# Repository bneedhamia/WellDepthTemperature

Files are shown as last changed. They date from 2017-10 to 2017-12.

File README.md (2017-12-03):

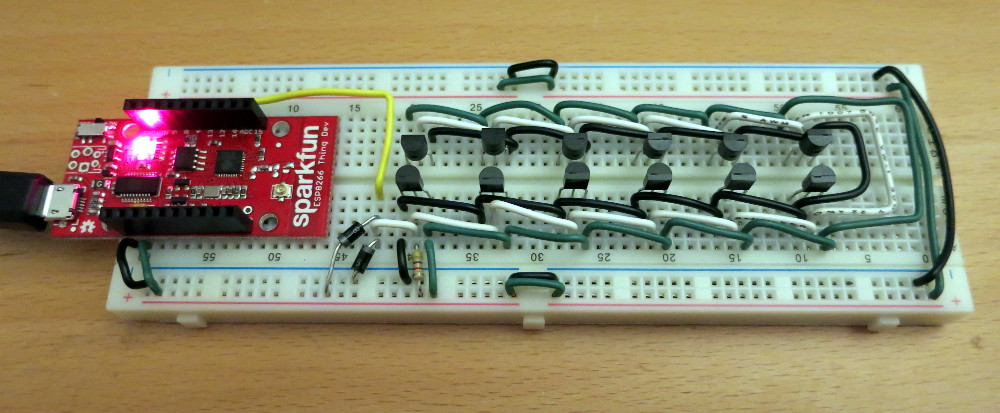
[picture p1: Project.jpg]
The Project so far

# WellDepthTemperature
An Arduino Sketch for a Sparkfun ESP8266 Thing Dev board, using multiple MAX31820 temperature sensors to estimate the height of water in a well tank.

This is a WORK IN PROGRESS. The state of the project: It currently connects to the local WiFi access point, reads the number of connected temperature sensors, and prints the 1-Wire address of each of them. It periodically reads the temperature from each of 12 sensors and performs an Https Post to a php page on needhamia.com that stores the data
in an SQL database. I'm designing the 3D printed junction boxes now, and soldering all the parts that will go into those boxes. See Diary.odt for details, remaining work, and progress.

Theory of operation: The side of the well tank is cooler below the level of the water than it is above that level. I plan to hot-glue a series of temperature sensors to the tank exterior, in a vertical line. Then I should be able to periodically measure the temperature at each sensor, estimate which sensors are below the water line, and translate that knowledge into an estimate of the level of the water in the tank.

I know that this method won't work when the ambient temperature of the well house is near the temperature of the water being pulled out of the well. I expect that won't be the case in the middle of a summer day, when we usually run out of water.

I chose this method over more reliable and direct methods because, compared to them, it's non-intrusive: I don't have to put anything in the tank, on the lid inside the tank, or in the pipes to or from the tank.

The current Arduino Sketch requires a Sparkfun ESP8266 Thing Dev board, a few MAX31820 temperature sensors, Cat6 cable, and some discrete parts (diodes, resistor). Details are in the .ino Sketch PIN_ definitions and in BillOfMaterials.ods.

Next steps: Construct the 1-wire bus and the plugs for the sensors.

## Files
* BillOfMaterials.ods = the parts list.
* BreadboardCase.FCStd = the FreeCAD design file for the ESP2866 circuit case (in progress). I will add the corresponding .stl files once I'm happy with the case design.
* createtables.sql = an SQL file to import into MySQL to create the well depth database table.
* diagrams.odp = project diagrams.
* Diary.odt = my journal/diary of the project, with design details.
* LICENSE = the project GPL2 license file.
* Project.jpg = a photo of the project so far.
* README.md = this file.
* ThreeJackCase.FCStd = the FreeCAD design file for the case for 3 RJ45 jacks.
* ThreeJackCaseBase.stl = the ready-to-print file for the base of the RJ45 case. Print right-side up, with no supports, raft, or brim. I designed it for PLA.
* ThreeJackCaseLid.stl = the ready-to-print file for the lid of the RJ45 case. Print UPSIDE-DOWN (lid top on the print bed), with no supports, raft, or brim. I designed it for PLA.
* webInstallation.odt = instructions on how to install the Sketch and web service.
* WellDepthTemperature.ino = the ESP8266 Arduino Sketch.
* WellDepthTemperature.fzz = the Fritzing (circuit wiring) diagram.
* welldepthconfig.php = site-specific PHP .ini-format configuration data, such as the sql database name.
Place this file in the same directory on your web site as welldepthpost.php.
* welldepthpost.php = the php web page that receives the Arduino's HTTPS POST request.

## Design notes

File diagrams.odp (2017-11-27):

## 1-Wire Bus Connections

Well Water Storage Tank

Senses ambient

temperature

Senses tank wall

temperature

= CAT6 cable

= MAX31820 sensor

= Three Jack Case

= Breadboard Case

ESP8266, etc.

Power (Mains)

plug

## Well Temperature Dataflow

MAX31820 Temperature

Sensors on the 1-wire bus

Server (Needhamia.com)

Server’s

PHP Web Service

MySQL

Database

ESP8266

Arduino Sketch

WiFi

Hotspot

HTTPS

Temperatures and

well tank depth estimate

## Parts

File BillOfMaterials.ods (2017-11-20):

Bill Of Materials for Well Depth Sensor |  | All values are in US Dollars
Count | Name | Supplier | Part Number | Cost each | Total | Url | Notes
1 | SparkFun ESP8266 Thing - Dev Board | Sparkfun | WRL-13711 | $15.95 | $15.95 | https://www.sparkfun.com/products/13711
2 | Arduino Stackable Header - 10 Pin | Sparkfun | PRT-11376 | $0.50 | $1.00 | https://www.sparkfun.com/products/11376 | To plug wires into the ESP8266 Thing Dev board
1 | Wall Adapter Power Supply - 5.1V DC 2.5A (USB Micro-B) | Sparkfun | TOL-13831 | $7.95 | $7.95 | https://www.sparkfun.com/products/13831 | This supply powers the ESP8266
12 | One-Wire Ambient Temperature Sensor - MAX31820 | Sparkfun | SEN-14049 | $1.95 | $23.40 |  | TODO finalise the number used. Available for a little less at Digikey: https://www.digikey.com/product-detail/en/maxim-integrated/MAX31820MCR/MAX31820MCR-ND/4271348
10 | Resistor 4.7K OHM 1/4W 5% AXIAL | Digikey | 4.7KQBK-ND | $0.06 | $0.60 | https://www.digikey.com/products/en?keywords=4.7KQBK-ND | We need only 1, but they're useful enough to buy at least 10
10 | Diode Standard 400V 1A Through Hole DO-41 | Digikey | 1N4004RLGOSCT-ND | $0.18 | $1.80 | https://www.digikey.com/product-detail/en/on-semiconductor/1N4004RLG/1N4004RLGOSCT-ND/822810 | Need only 2 for the 1-Wire bus, but they're useful enough to buy at least 10
1 | Breadboard - Self-Adhesive (Half size) | Sparkfun | PRT-12002 | $1.18 | $1.18 | https://www.sparkfun.com/products/12002
1 | Cable Matters Cat6 Snagless Ethernet Patch Cable in White 20 Feet (about 6 meters) | Amazon | B00G9BMZI4 | $14.99 | $14.99 | https://www.amazon.com/Cable-Matters-Snagless-Ethernet-Patch/dp/B00G9BMZI4 | You'll cut this and make your own cable ends. This is cheaper than bulk unless you need 300 meters or more
1 | Cable Matters (100-Pack) Cat 6 RJ45 Modular Plugs for Stranded UTP Cable | Amazon | B004D5RFCE | $12.95 | $12.95 | https://www.amazon.com/gp/product/B004D5RFCE
1 | Cable Matters 4-Pack RJ45 Color Coded Strain Relief Boots in Blue (50 Pieces per Pack) | Amazon | B0049QNV3E | $11.99 | $11.99 | https://www.amazon.com/Cable-Matters-4-Pack-Strain-Relief/dp/B0049QNV3E
37 | SparkFun RJ45 Breakout board | Sparkfun | BOB-00716 | $0.95 | $35.15 | https://www.sparkfun.com/products/716
37 | RJ45 8-Pin Connector | Sparkfun | PRT-00643 | $1.50 | $55.50 | https://www.sparkfun.com/products/643
8 | Break Away Headers – Straight | Sparkfun | PRT-00116 | $1.50 | $12.00 | https://www.sparkfun.com/products/116 | For the RJ45 Breakout boards. 8 pins per board.
12 | 3D Printed, 3 Jack, RJ45 Box | -custom- |  |  |  | ThreeJackCase.stl | Custom part. Design file is in GitHub
1 | 3D Printed breadboard case | -custom- |  |  |  | BreadboardCase.stl | Custom part. Design file is in GitHub
 | TODO heat shrink tubing |  |  |  | $0.00
 | MORE TO COME |  |  |  | $0.00
 |  |  |  |  | $0.00
 |  |  |  |  | $0.00
Total (Parts) |  |  |  |  | $194.46
Tools and Hookup Wire
1 | C2G/Cables to Go 19579 RJ11/RJ45 Crimping Tool with Cable Stripper (Black/Blue) | Amazon | B00006HTBR | $28.27 | $28.27 | https://www.amazon.com/gp/product/B00006HTBR | There are less expensive ones, but I liked the reviews on this one.
 | TODO glues/epoxies
1 | Hookup wire, solid, 22Awg, white | Sparkfun | PRT-08026 | $2.50 | $2.50 | https://www.sparkfun.com/products/8026 | Signal wires
1 | Hookup wire, solid, 22Awg, black | Sparkfun | PRT-08022 | $2.50 | $2.50 | https://www.sparkfun.com/products/8022 | Ground wires
1 | Hookup wire, solid, 22Awg, red | Sparkfun | PRT-08023 | $2.50 | $2.50 | https://www.sparkfun.com/products/8023 | Power wires
1 | Hookup wire, solid, 22Awg, yellow | Sparkfun | PRT-08024 | $2.50 | $2.50 | https://www.sparkfun.com/products/8024 | Arduino signal wires
Total (Wire and Tools) |  |  |  |  | $38.27

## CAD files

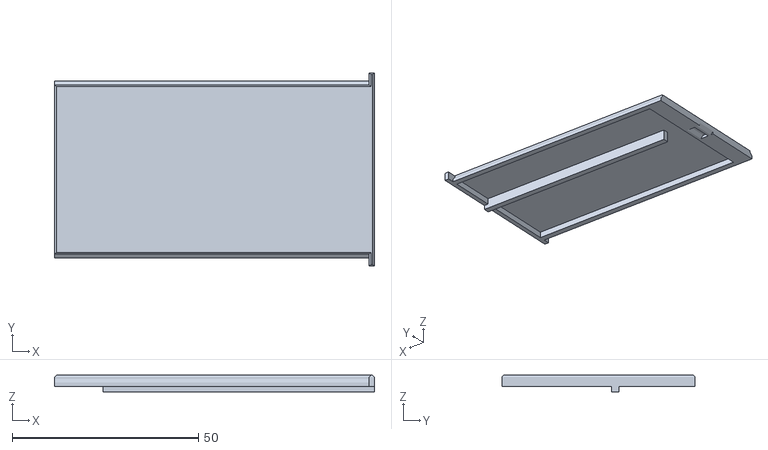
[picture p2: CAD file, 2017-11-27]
ThreeJackCaseLid.stl
86.0 x 52.0 x 4.45

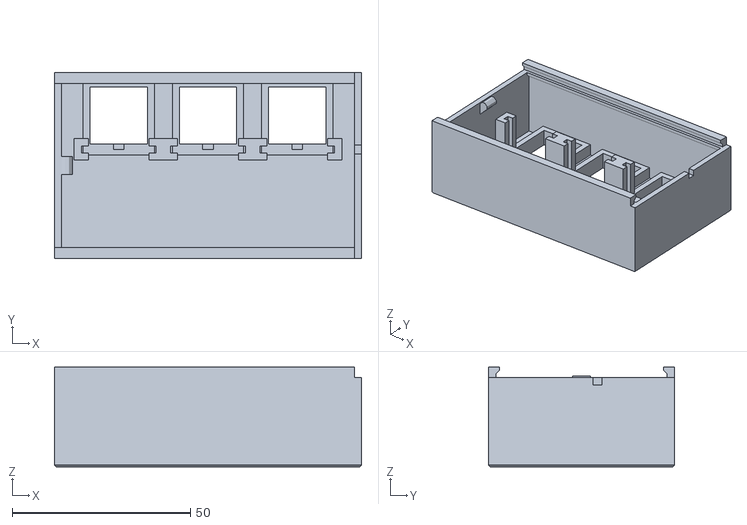
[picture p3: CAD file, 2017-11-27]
ThreeJackCaseBase.stl
86.0 x 52.0 x 28.0

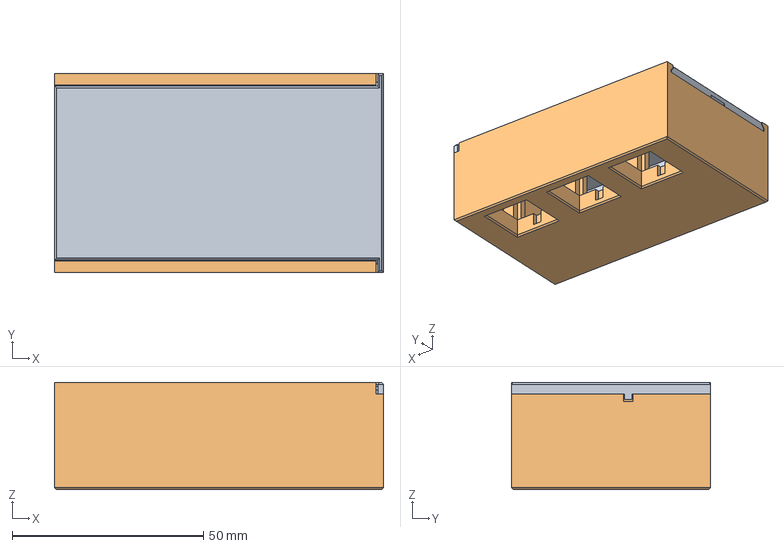
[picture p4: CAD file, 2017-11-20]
ThreeJackCase.FCStd
86.0 x 52.0 x 28.0 mm
partLidComplete
partBaseComplete

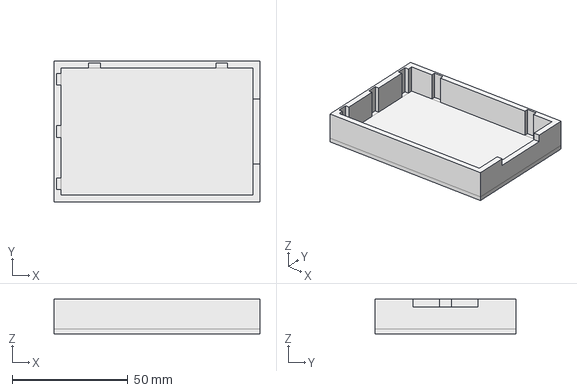
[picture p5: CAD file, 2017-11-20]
BreadboardCase.FCStd
89.0 x 61.0 x 15.0 mm

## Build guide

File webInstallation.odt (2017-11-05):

# Installing the Well Depth Web Service

## Choose your names, paths, and passwords

To perform the steps below, you will first make a set of choices. NOTE: For security, all the usernames and all the passwords should be different from each other.

1. The web server path to your welldepth php files. For example, under webroot, "webapps/welldepth".
2. The application username and password for your well depth web service. For example, "charles" and "wonderland".
3. The database name of the depth SQL database you will create. For example, "welldepth".
4. The database hostname of the database you will create. Your SQL provider can give you this name.
5. The database writer username and password for the depth SQL database. For example, "wellwriter" and "ladyofthelake".
6. The database reader username and password for the depth SQL database. Nothing in the current implementation uses these names; they'll be useful when you write a GET web service. For example "wellreader" and "humanity".

## Create the empty sql database

Using your server-specific methods (which your server provider can tell you):

1. Create a database by the name you chose. For example, welldepth.
2. Create the database writer and reader names and passwords, and give those database users appropriate access to your database: the writer should be able to insert; the reader should be able to Select.
3. Execute the SQL query from the file createtables.sql. That should create the database depth table.

## Modify the PHP configuration file

Modify welldepthconfig.php.

For security, it's a good idea to make these modifications on a copy of the file outside the WellDepthTemperature folder. If you make these changes to your WellDepthTemperature folder file, it's easy to accidentally commit those changes, revealing your passwords to anyone who can read your git repository.

1. Change the value of app_username to your application username (for example, charles).
2. Change the value of app_password to your application password (for example, wonderland).
3. Change the value of sql_hostname to your database hostname.
4. Change the value of sql_database to your well depth sql database name (for example, welldepth).
5. Change the value of sql_writer_username to your database writer username (for example, wellwriter).
6. Change the value of sql_writer_password to your database writer password (for example, ladyofthelake).
7. (the reader username and password are not currently used, so they are not in welldepthconfig.php)

## Upload the PHP files

On your web server:

1. Create the path to your well depth files. For example, under your web root, create a webapps folder, and under that, a welldepth folder.
2. Copy your modified welldepthconfig.php to the new welldepth folder.
3. Copy welldepthpost.php to the new welldepth folder.
4. If necessary, set the permissions on those files as appropriate to your web server. You may need to ask your web administrator to find how to do this.

## Modify the ESP8266 EEPROM strings

1. Copy https://github.com/bneedhamia/write_eeprom_strings
2. Modify the initialization of STRING_NAME[] to the code given in WellDepthTemperature.ino.
3. Run the modified write_eeprom_strings.ino Sketch
4. When prompted, enter the WiFi hotspot credentials and the application username and password you chose (for example, charles and wonderland).

## Test the configuration

Run WellDepthTemperature.ino, with the Serial Monitor running. Normal output should look something like:

21.19, 20.12, 21.12, 20.44, 20.50, 20.69, 21.75, 20.69, 20.50, 21.25, 21.19, 20.37
Connected to needhamia.com
Reading response:
HTTP/1.1 200 OK
Date: Sun, 05 Nov 2017 21:35:26 GMT
Server: Apache
Content-length: 16
Connection: close
Content-Type: application/json

{"succeeded": 1}
connection closed.

If there are local (ESP8266) errors, the Sketch should print them. If there are web-service errors, the "succeeded" value should be 0, and there should be a "response" value that gives some information about the error.

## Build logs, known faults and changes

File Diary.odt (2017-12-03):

# Well Depth Temperature Project Diary

The idea is to periodically post how full our well storage tank is, using digital temperature sensors fastened to the side of the tank at more-or-less regular intervals. Being on a well, we'd like to avoid the rare surprise of finding the well tank nearly empty due to a leak or water overuse.

Theory of operation: the code will read the temperature at each sensor, then find the point where the temperature drops (where the level of the cold well water is).

## Main parts

- 1 Sparkfun EPS8266 Thing Dev board. It's more or less Arduino compatible and has an integrated Wifi module. Wifi will be used to send the data to the cloud. The Thing will be powered by wall power, via a USB adapter. Note: this is a 3.3V part.
- about 10 MAX31820 one-wire temperature sensors. Each one will be hot-glued to the exterior of the well tank, in a vertical line. I may run one to the outside, to get an exterior temperature reading. Note: this is a 3.3V part.
- Cat6 cable used for the 1-Wire bus. Cat5 or Cat6 is recommended by Maxim in their Guidance doc.

### Notes

- https://github.com/PaulStoffregen/OneWire is the latest OneWire library, which supports the ESP8266. I installed this in the Arduino/libraries folder.
- https://github.com/milesburton/Arduino-Temperature-Control-Library talks to the MAX31820 using the OneWire library. It seems to be the MilesBurton code many sites point to, that has moved.
- https://cdn.sparkfun.com/datasheets/Sensors/Temp/MAX31820.pdf is the Datasheet for the MAX31820.It says to put a 4.7K resistor between data and Vcc at the master (processor) end.
- http://pdfserv.maximintegrated.com/en/an/AN937.pdf application note explaining (among many other things) the Search ROM command to be used to discover the addresses of the sensors on the bus. https://www.maximintegrated.com/en/app-notes/index.mvp/id/187 is a web page with a quick discussion of that search algorithm. Fortunately, the OneWire library supports the Search function, so I don't need to write code to do it.
- http://espressif.com/en/products/hardware/esp8266ex/resources, which points to the ESP8266EX (the Sparkfun Thing Dev board's processor) datasheet.
- Q: does the sensor library cause long (>20ms) delays that might interfere with the WiFi functionality?
- I need to run at least 8 feet of 1-wire bus over twisted pair. That's going to be quite an antenna. Find how to run long 1-wire busses. https://www.maximintegrated.com/en/app-notes/index.mvp/id/148 looks like a useful discussion of this topic, and references the Maxim 1-wire datasheet. It says to not use the parasitic power design that many people use. May (probably not) need a termination resistor between power and ground and data and ground at the end of the wire.
- The ESP8266 WiFi library documentation (https://arduino- (https://arduino-esp8266.readthedocs.io/en/latest/esp8266wifi/readme.html)esp8266.readthedocs.io/en/latest/esp8266wifi/readme.html (https://arduino-esp8266.readthedocs.io/en/latest/esp8266wifi/readme.html)) points out that the secure client doesn't support TLS 1.2. NOTE: Because of this, your HTTPS communications can be read by a hacker.
- The top temperature sensor must always be above the water line, so the Sketch can distinguish a full tank from an empty tank.
- The straight side of the tank is about 65" tall. The wall socket is about 32" from the tank.
- To read a site's SSL Certificate using chrome:
  - Browse to the site you want to read the certificate of.
  - Select hamburger menu / More Tools / Developer Tools
  - Click the tab labeled Security
  - Scroll down slightly and click the button labeled View Certificate
  - In the resulting dialog, click the tab labeled Details
  - Click Copy to File...
  - Click Next
  - Select Base-64 encoded X.509 (.CER)
  - Click Next
  - Choose a destination name, e.g., mysite.cer
  - Click Next
  - Click Finish
- To generate the SHA1 Fingerprint of a site certificate (.CER) file under Windows:
  - Open Git Bash
  - cd to the folder containing your saved .cer file.
  - openssl x509 -noout -fingerprint -sha1 -inform pem -in certificate-file.cer
  - Convert the string of bytes into a byte array initializer for C++, for example:
    - opensll output: 36:33:CC:B8:5C:76:B8:0D:BF:79:21:0E:18:46:2E:63:D5:CD:4C:FA
    - replace all the ":" characters with a single space each.
    - corresponding C++ string: const char* fingerprint = "36 33 CC B8 5C 76 B8 0D BF 79 21 0E 18 46 2E 63 D5 CD 4C FA";
- To base64 encode a string, such as the username:password method used in http Basic Authentication. Suppose for example your user is "charles" and your password is "wonderland" (which is a poor choice):
  - echo "charles:wonderland" | openssl enc -base64 which produces: Y2hhcmxlczp3b25kZXJsYW5kCg==

## To Do

1. Test-fasten one junction box to the well tank, with a heavy Cat6 cable connected, to see whether the weight will pull the junction box off the well tank.
2. Decide which two twisted pairs of wires of the Cat6 cable's 8 wires to use for the 1-wire bus (ground and data, ground and 3.3V).
3. Solder all the jumper wires in quadruplets, each quadruplet connecting the corresponding pins of one RJ45 connector together. There will be 4 sets of those 3 jumper ends per junction box.
4. Build the 8-foot-long bus with the desired spacing of the temperature sensors and get that working.
5. Install the whole thing and make sure it's uploading temperatures to Needhamia.
6. Use GoDaddy MySQL to export the database of a few days to .csv format.
7. Using the .csv data, design an algorithm to estimate the well depth from the temperature data.

## Diary

### December 3, 2017: Fritzing

Took a few minutes and did the Fritzing diagram for the breadboard. It has only a few parts, to make the 1-wire bus work.

### November 26, 2017: Lots of soldering

Today I soldered all the RJ45 jacks to their breakout boards and headers – 576 connections in all!

### November 19, 2017: More 3D Design

Did a quick turn on the base of the breadboard case, so I can make measurements of what the lid should be like. Found I'd forgotten to set the width of the cutout for the tail of the ESP8266 board. Set that width (hopefully) correctly.

Did a complete design of the base and lid for the 3 jack box. Decided on a snapping-closed, sliding lid for now. Started a test print.

Turned in the Sparkfun order for the pile of RJ45 jacks, breakout boards, and headers for them. Brought the Bill Of Materials up to date with the new design of the 1-wire bus: 3D printed boxes with 3 RJ45 jacks per. Still need to update it for plugging stock Cat6 cables between the boxes. It's more expensive than modding wall mount RJ45 boxes, but it's more modular and reusable. ...and it gives me a chance to design 3D printed boxes.

### November 18, 2017: Designing 3D printed cases

I had ordered and received 5 RJ45 jacks and breakout boards from Sparkfun. They arrived a couple days ago. I soldered the breakout boards to the jacks, then started considering how to modify the RJ45 wall mount boxes to work for the project.

The more I considered how to mod the boxes, and the more I looked at the RJ45 jack + breakout, the more I came to like the idea of making a 3D printed box that holds 3 RJ45 jacks and their breakout boards, with jumpers connecting the 3 breakout boards' pins. That way, the whole 1-wire bus is modular and plugged together. The older way I was thinking of would have required me to successfully wire all of the boxes for the sensors as one long wire – if I broke a wire at any point, or if I decided to add another sensor, I would have had to do the whole thing over. So I decided to go with a 3D printed box.

Designed and printed a test base for one RJ45 jack + breakout board, to test clearances. The test result was very good: the board clearance is perfect; the jack clearance could use another 0.5mm in each direction.

Did a second version of the design: a base of a rectangular box, that holds 3 (adjusted size) jack holders. I'm seeing some issues with how to open the box when it's fastened to the side of the well tank, but not enough to worry about just yet. Did another test print, which came out fine as far as RJ45 fit. Now I need to design the dimensions and closing mechanism of the box.

Set up a Sparkfun order of a pile of the RJ45 jacks, breakout boards, and short f/f jumper cables (so I don't have to make my own cable ends).

Designed a test print of the clearances around the half-sized breadboard (which has dovetail connectors to make cutouts for). Did a test print of that. Found I needed to move a couple of the cutouts for the dovetails. Moved them, then made more of a box base out of it.

### November 10, 2017: Connectivity looks good

The breadboard in the well tank room seems to still be working fine, so I don't think I'll have any connectivity issues in the real thing.

### November 8, 2017: Testing well-tank connectivity

I reprogrammed the EEPROM to talk to the AP in the garage, then moved the breadboard with the ESP8266 and 12 temperature sensors to the well tank room, and plugged it in using a Pi power supply (micro USB, 5V, 2.4A output).

It seems to be working fine. Within a few minutes it had uploaded 16 records, and the temperatures look reasonable (about 9 degrees C). I'll let it run for a couple days and see how it's doing.

After looking at how to adapt the RJ45 connector I bought for the breadboard, I instead ordered RJ45 connectors and breakout boards from Sparkfun. Those breakout boards will let me directly plug an RJ45 connector into the breadboard, reducing the effort of building the ESP8266-to-1-wire-bus connection.

### November 5, 2017: SQL

I created a MySQL database on needhamia.com, creating a write-read user (the HTTPS POST receiver) and a read-only user (unused for now). Saved the credentials so I can put them in the PHP config file.

Created the table layout (createtables.sql). Wrote the SQL code based on the older weight database PHP app I wrote a long time ago. Spent time debugging simple errors (typos in the SQL query).

The PHP and Sketch now successfully upload the well depth and temperatures to the SQL database.

Successfully ran the Sketch for more than 24 hours without problems, then stopped because a day's worth of test is enough for now.

### November 4, 2017: Working out security and authorization

I found a good discussion at https://stackoverflow.com/questions/4150507/how-can-i-use-basic-http-authentication-in-php where people seemed to say that Apache mod_cgi (which is likely what GoDaddy is running) won't pass Basic Authorization credentials to the php page, for security reasons. So I think I'm making the expedient, but not terrible for this application, decision to pass a username and password via Post parameters rather than using Basic Authorization.

Looking into how to read a local config file from php, so that I can separate the sql username/password from the application username/password. I should probably write a Security.odt file for this Sketch and Php page, describing the security measures I've chosen and what their weaknesses are.

Remembered that a web site's robots.txt file simply keeps google and other honest robots from indexing a non-content folder (such as my php folder). A bare .ini file is still readable as text – oops. Found a comment in the description of php .ini files, http://php.net/manual/en/function.parse-ini-file.php (http://php.net/manual/en/function.parse-ini-file.php), that shows how to make a config file a .php file as well, so that if a web user attempts to read it, it will simply quit rather than sending the text of the file to the user.

Successfully tested a php config file and dummy web service that echoes the config.

Added code to the Sketch to read the app username and password from EEPROM, and send those as HTTPS POST parameters. Added code to the php page to validate the Post username and password against the values in the config file. Work remains on urlencoding the Post parameters.

Added Sketch code to the rest of the fields (well depth estimate, sensor temperatures) in the POST request. Modified the PHP code to read those values. Now everything is ready to add the database.

### November 3, 2017: Writing the PHP page

I found a simple example of reading the User and Password from the Basic Authorization header, at http://php.net/features.http-auth. I created a php page taht is a copy of that page, did a GET on that page from the ESP8266. The result included "HTTP/1.1 401 Unauthorized" – I think the problem is that the basic authentication is being checked by the Apache server (and failing) before my page gets it. I decided to try a POST with a username and password as POST parameters rateher than any real authentcation scheme.

Successfully sent a simple POST request to a simple POST reader php page.

Next step: urlencode the POST parameters on the ESP8266 side. See https://github.com/zenmanenergy/ESP8266-Arduino-Examples/blob/master/helloWorld_urlencoded/urlencode.ino for example code. I'm a little surprised the ESP8266 library doesn't seem to have an urlencode function.

### November 2, 2017: Debugging HTTPS GET and authorization

Based on the HTTPS request sample I found yesterday, I've added code – as a test – to perform an HTTPS GET request on one of the ordinary HTML pages on my site, needhamia.com. Later I'll change this into the HTTPS request to upload the temperatures.

The test request is:

GET /sample-page HTTP/1.0
Host: needhamia.com
User-Agent: ESP8266HttpsClient
Connection: close
(blank line to indicate the end of headers)

I use HTTP/1.0 instead of 1.1 so that the site doesn't used chunked transfer-encoding, which is harder to parse.

The site response headers are:

HTTP/1.1 200 OK
Date: Thu, 02 Nov 2017 19:34:37 GMT
Server: ApacheLink: <https://needhamia.com/wp-json/>; rel="https://api.w.org/", <https://needhamia.com/?p=2>; rel=shortlink
Cache-Control: max-age=3600
Expires: Thu, 02 Nov 2017 20:34:37 GMT
Vary: Accept-Encoding
Connection: close
Content-Type: text/html; charset=UTF-8

If I request HTTP/1.1, the site responds with Transfer-Encoding: chunked, which prepends every big block of text with an ascii byte count. Requesting 1.0 seems to fix that.

Bug: the response is significantly truncated. It ends in mid-html. I don't yet know why. Since I'll be dealing with substantially shorter responses, I'm not going to worry about it.

Now that I think about it, I'll probably eventually replace this code with code to do a client.get() if I can.

I spent some time digging up authentication methods to use between the ESP8266 and the (php) web service. It looks like I probably want to use the "Authorization: basic 4738d838u38" header value, where the string "username:password" is base-64 encoded.

Found openssl does base64 encoding. Added a Basic Authorization header to the client request, just to see whether Apache would get in the way.

### November 1, 2017: Making sense of site SSL Certificates

ESP8266 Https support requires the SHA1 Fingerprint of the site's Certificate. Getting that certificate is a bit tricky. On the good side, I found https://knowledge.symantec.com/support/identity-protection-support/index?id=SO28771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 (https://knowledge.symantec.com/support/identity-protection-support/index?id=SO28771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) which explains that the Open SSL command to calculate an SHA1 fingerprint from a .crt certificate file is:

openssl x509 -noout -fingerprint -sha1 -inform pem -in [certificate-file.crt]

Git Bash (a Windows Git command set) supports openssl – that is, you can do openssl commands under Windows from Git Bash.

I also found that Chrome provides a way to download the SSL Certificate (see notes, above). I don't yet know how to go from a .cer file (that Chrome generates) to a .crt file (that openssl reads).

https://stackoverflow.com/questions/642284/apache-with-ssl-how-to-convert-cer-to-crt-certificates seems to say you can just rename a .cer file to a .crt file; that they contain the same data in the same format, but other responses on that page suggest there's more to it than that.

I saved the Needhamia.com certificate to base-64 encoded format, then gave the following command:

openssl x509 -noout -fingerprint -sha1 -inform pem -in needhamia64Cert.cer

A fingerprint came out – I'm not sure if it's the right one yet.

https://github.com/esp8266/Arduino/blob/master/libraries/ESP8266WiFi/examples/HTTPSRequest/HTTPSRequest.ino is an example of using an SSL certificate fingerprint from an ESP8266.

Based on the example, I modified the Well Sketch to 1) attempt to verify the fingerprint, and 2) attempt to perform a simple HTTP GET request and print the response.

### October 27, 2017: Learning about Punch Down blocks

I chose the "Punch Down" type of RJ45 box instead of "Screw down" type, because the reviews seemed to say that Punch Down makes a better connection and is easier to use. Little did I know I was entering a new world.

The first thing I learned is that Punch Down blocks require a Punch Down tool. The second thing is that there are several different types of Punch Down blocks. After serarching a bit, I found the Wikipedia page on Punch Down Block, which says "A 110 block is often used in residential telephone and Cat 5 wire systems" – so it sounds like 110 is what I want. That page also says that punching down multiple wires into one slot should be avoided, because it leads to bad connections. So it sounds like I'll be soldering the ingoing, outgoing, and internal Cat6 wires together, then punching down the internal Cat6 into the punch down block.

I think I'll make the first block of the 1-wire bus be set up to have the Arduino 1wire bus plugged in via an RJ45 connector.

Examining the two-ended blade that came with the punch down tool: the blade is marked "110", and one end is marked "cut". The end marked "cut" has a little knife edge on the side of the blade, that cuts the wire as it's punched down – be sure to have the cut end on the outside of the punch; otherwise you'll cut off the wire that you're trying to punch down, instead of simply cutting off the excess wire you're punching down. It all seems quite exotic right now.

So I think I now have all the parts and tools required to build the 1-wire bus that will run up the side of the well tank.

### October 26, 2017: Bought the final bus parts

I stopped by our local electronics cable supplier and bought a 20 foot (about 6 meters) Cat6 cable and 20 RF45 strain relief boots. Now I just have to wait for the RJ45 parts from Amazon, which should arrive today.

### October 23: Ordered parts for the bus construction

I'm now thinking of a 2 part bus: 1) Connect each temperature sensor to an RJ14 (4 wire) via a short cable, and 2) Construct each connector on the bus out of a common "Surface Mount" phone jack, with two holes drilled in the jack side, for the incoming and outgoing parts of the 1-wire bus.

The phone jack has me a bit puzzled. After hunting around Amazon for a while, I landed on "Leviton C2452-W Surface Mount Phone Jack, 4 Conductor, White": https://www.amazon.com/Leviton-C2452-W-Surface-Mount-Conductor/dp/B00002N7JD.

After trying to find a combination of jack box, crimper, and plugs, I decided to go with RJ45 instead of RJ14. RJ45 is much more popular, and the crimper and parts may be more useful later.

Ordered the "Cable Matters (5 Pack) Cat6 RJ45 Surface Mount Box - 1 Port in White" https://smile.amazon.com/Listed-Cable-Matters-Surface-Mount/dp/B00IO3H88C, Cable Matters (100-Pack) Cat 6 RJ45 Modular Plugs for Stranded UTP Cable, https://smile.amazon.com/Cable-Matters-100-Pack-Modular-Stranded/dp/B004D5RFCE (https://smile.amazon.com/Cable-Matters-100-Pack-Modular-Stranded/dp/B004D5RFCE), and C2G/Cables to Go 19579 RJ11/RJ45 Crimping Tool with Cable Stripper (Black/Blue), https://smile.amazon.com/C2G-Cables-Go-19579-Crimping/dp/B00006HTBR. I'll need to buy Cat6 cable from the local cabling shop.

### October 22: More Coding

Did a lot of cleanup/messing-with the code. Added error testing on the WiFi connection: now if the ssid or password is incorrect the Sketch reports it rather than waiting forever.

I realized that the top well-tank temperature sensor must always be above the water line; otherwise, we can't distinguish between the tank being full and empty.

Read up a bit on the ESP8266 WiFi library (https://arduino-esp8266.readthedocs.io/en/latest/esp8266wifi/readme.html). Disappointed to find that the "secure" Https code doesn't support TLS 1.2 – that is, it supports only the encryption type that has been hacked.

Had a few thoughts on the 1-wire bus construction: To make it easy to replace a bad/rusted sensor, I want to plug the sensor in to the bus via an RJ25 plug. I might 3D print a 3-plug box where there are two holes in the bottom for the 1-wire bus in and out (on the bottom to keep moisture from dripping in), and an RJ25 plug for the sensor. I'll put the sensor on a short wire for strain relief and to enable adjustment of the sensor placement.

Tested the "sensor is not on the bus" code by unplugging one of the sensors from the breadboard. The Sketch appropriately reported -127 degrees C for that sensor.

### October 21, 2017: Coding

I put 4 more sensors on the breadboard and added code to print the 1-wire address of each sensor. The code properly reported the addresses of all 6 sensors. Then I swapped out the sensors for the other 6, as an acceptance test. The second 6 reported their addresses properly.

Wrote and tested code to periodically read the temperature – asynchronously – from each sensor. Added an array of sensor addresses, in order of distance from the ESP8266 rather than the search order. The search order is based on the addresses and is unrelated to their position on the 1-wire bus.

Now that the temperature has settled, the output reads 22.1, 20.8, 21.6, 20.7, 20.6, 20.6. That list has a range of 1.5 degrees C, which is 2.7 degrees Fahrenheit. That makes sense, because the MAX31820 datasheet specifies an accuracy of +/-0.5 degrees C (a range of 1 degree C), and the first sensor is close to the processor – I'd expect it to be a little hotter.

I expect the temperature differences I'm interested in will be closer to several degrees C.

I think the tricky part of the project will be the fastening of the sensors to the 1-Wire bus: I'd like to make it possible to easily replace (unplug and replug) a faulty sensor when one eventually fails. A lot of projects use RJ25 (phone plug) connectors because they are reliable and the infrastructure supporting them (plugs, sockets, crimpers, etc.) is well supported.

I breadboarded all 12 sensors and added over/undervoltage diodes, and the system still works.

Looking for RJ45 connectors, etc., I found the Sparkfun RJ45 breakout board, which looks useful: https://www.sparkfun.com/products/716. There's the RJ45 connector as well: https://www.sparkfun.com/products/643.

### October 20, 2017: Circuit testing

The parts arrived last night. Today I soldered the Arduino 10-pin headers to the two ESP8266 Thing Dev boards I'd ordered (one plus one spare), and did some basic acceptance testing: Blink downloads and runs, I can write to EEPROM, and I can connect to a wifi access point.

Wiring up the temperature sensors, I was a bit confused by what seems to be a "+" label next to what the documentation describes as the GND pin – but yes, that's true: as the flat side of the part is facing you and the pins are pointing down, the pins are in 1, 2, 3 order: GND, DQ (Data), Vdd (power).

In choosing the data pin, I wanted to avoid the weird ones of the ESP8266 Thing Dev board: GPIO0 and GPIO2 have 10K pullups on board; GPIO15 has a 10K pulldown resistor on board; GPIO5 is connected to the on-board LED. GPIO16 sounds safe [That turned out to be not true].

I wired up two MAX31820s and ran a simple Sketch to report the addresses of the sensors. It reported "0 temperature sensors responded." Hmm. With a multimeter I checked that the GND to 3V3 voltage (3.29V), that GND was connected (had nearly zero resistance) to the temperature sensor pin 1s, that GPIO16 was connected to the sensors' pin 2s, and that pin 3V3 was connected to the sensors' pin 3s. I also checked that when the board was powered up the DQ pins were pulled high (about 3.3V).

Looking at the DallasThermometer and OneWire library implementations, I see there is low-level ESP8266 I/O code in the OneWire library – I wonder if that's the problem. I verified that ARDUINO_ARCH_ESP8266 was defined by adding a #if defined(ARDUINO_ARCH_ESP8266) clause to my Sketch that would cause a compile error – it did. Similarly I verified that ARDUINO_ARCH_ESP32 is not defined.

I found in OneWire.h under the EXP8266 conditional defines:

#define PIN_TO_BITMASK(pin) (1 << pin)

Comparing that to an answer about ESP8266 direct input, at http://www.esp8266.com/viewtopic.php? (http://www.esp8266.com/viewtopic.php?f=32&t=6703)f=32&t=6703 (http://www.esp8266.com/viewtopic.php?f=32&t=6703), I see that code says

#define digitalPinToBitMask(pin) (1UL << (pin))

So I changed the OneWire.h conditional code to read

#define PIN_TO_BITMASK(pin) (1UL << pin)

Analysis: 1 in the above original OneWire.h code is of type int, which is only 16 bits. Shifting it by 16 would make it zero, which wouldn't work at all. Unfortunately, running the modified code still identified zero sensors.

Reading on, I found a suspicious pair of lines in OneWire.h:

DIRECT_WRITE_LOW(reg, mask);

DIRECT_MODE_OUTPUT(reg, mask); // drive output low

In other words, it first tries to write the pin, then sets the pin to output. Naively, that sounds backward to me. So on a whim I reordered the mode and output lines (3 occurrences I recall) to put the mode setting before the attempt to write. For example:

DIRECT_MODE_OUTPUT(reg, mask); // drive output low

DIRECT_WRITE_LOW(reg, mask);

Rebuilt and tested. Still zero sensors detected. To check that my changes were being compiled in I added a deliberate compile error to OneWire.cpp, and it did cause a compile error in my Sketch. I then removed that compile error; recompiling the Sketch succeeded. So the changes I've made to OneWire.h and .cpp have indeed been compiled in.

With such fundamental bugs inthe OneWire library for ESP8266, I'm concerned about how much work I'm going to have to do to OneWire, and how to get those fixes in – because the OneWire library seems to imply there's an ESP8266 community version of OneWire.

To double-check that the ESP8266 Arduino library doesn't have a OneWire library, I removed the OneWire library from Arduino/libraries and compiled my Sketch. I did indeed get a compile error saying there's no OneWire.h. I then restored OneWire.h

Hunting for a more recent/official ESP8266 OneWire library, I found https://github.com/esp8266/Arduino/issues/1307, which ends with a note at the end of February 2016: "Since we have removed OneWire from this repository in favour of the official version, please open the issue at https://github.com/PaulStoffregen/OneWire." So it sounds like I'm using the correct version of the library.

Looking at the bug reports for the PaulStoffregen OneWire library, I found https://github.com/PaulStoffregen/OneWire/issues/27 says that pin 16 doesn't work because the ESP8266 Pin 16 requires special treatment in trying to do direct I/O. So it seems my using GPIO 16 was a bad idea.

Looking through more Issues against that repo, I see one where a person is using ESP8266, and in frustration created their own fork of the library, for their EPS8266 work. I'll try that library (https://github.com/bzub/OneWire).

I changed the data pin to D4 (which seems innocuous) and tried the new OneWire library. It worked! "2 temperature sensors responded." Just for thoroughness, I reverted to the original, unchanged PaulStoffregen version and found that worked too. So I'm staying with the PaulStoffregen version of OneWire since that seems to be more up to date.

The sketch now says: 2 temperature sensors responded. First sensor found: DeviceAddress x = {0x28, 0x48, 0xCE, 0xA8, 0x7, 0x0, 0x0, 0x85}; Created a github repo, now that some parts of the code are working.

### October 19, 2017: More parts decisions, research, and a little coding

I decided to use CAT3 (house phone wiring cable) instead of CAT6, mainly because I have a reel of it, but also because it's less expensive than CAT6. [Actually it turned out that the connectors are far more expensive than the wire.]

Realised that the OneWire library uses a single I/O pin for both input and output. I had hoped to use a TIP transistor to drive the output, but now I'm not sure how to use a single pin for normal input and to drive the base of the transistor. The OneWire library seems to support only one, bidirectional pin rather than one input pin and a separate output pin (as Maxim recommends for high-power 1-wire busses).

Good news! In phrasing a question for Sparkfun about how to construct a higher-power 1-wire bus, my re-reading of the MAX31820 datasheet seems to say that the part consumes only 5uA rather than 4mA, which means I can connect a bunch of them directly to an ESP8266 Thing pin (12mA max output) with no worries. So it looks like the hardware will be a piece of cake.

Read much of https://github.com/milesburton/Arduino-Temperature-Control-Library. Decided to try to use it rather than code my own stuff, because the functions seem non-trivial. Installed that library to Arduino/libraries. Added a #include of that library, and the Sketch compiled – that's a good first sign.

Wrote a little code to initialize the 1-wire bus and get first device address from the bus. It compiles, so I'm now ready for the hardware to show up (it should show up this afternoon).

### October 14: More research

Didn't yet find anything that says what I should use for an end-of-bus termination. Found the Maxim temp sensor datasheet describes a 4.7K pullup on the data line on the Arduino end.

Found the OneWire library takes care of the search function (and others). It sounds like the non-OneWire-library code should be small [That turned out to be not true].

Found what seems to be the MilesBurton code for talking to the temp sensors, at https://github.com/milesburton/Arduino-Temperature-Control-Library.

Sketched out the tasks to create the system.

### October 13: How to handle the long wire

The 1-wire bus for the temperature sensors will likely be about 10' (about 3m) long. That's long enough to worry about transmission line effects and noise immunity (or lack of it). Found a promising application note from Maxim: https://www.maximintegrated.com/en/app-notes/index.mvp/id/148 "Guidelines for Reliable Long Line 1-Wire Networks".

The guidelines report:

- Don't use a star network. A linear network (1 cable with taps every so often) sounds promising.
- Don't use the MAX31820 parasitic power mode in long 1-wire networks.
- The typical signal propagation speed in a phone cable is about 2/3 of the speed of light (they seem to say 10nS/m). For a 4m cable, that's about 40nS or 0.040uS, which I think I can ignore.

http://forum.arduino.cc/index.php?topic=336798.0 sounds like someone who is exploring the same configuration I am.

### October 8, 2017: initial coding

I've ordered the parts from Sparkfun. While I'm waiting for them to arrive, I'm writing some initial code. Installed the OneWire library, that supports ESP8266.
Hunting for a good temperature sensor library. https://github.com/milesburton/Arduino-Temperature-Control-Library looks promising, but has issues listed against it that suggest it doesn't do multiple sensors very well, and doesn't support async reading (which will be necessary to avoid too-long delays for the WiFi to tolerate) [November 8: that turned out to be untrue – it worked fine.]
I noticed each sensor sinks 4mA [That turned out to be untrue], so 10 will require the ESP8266 to source 40mA – I need to double-check whether it's able to do that.

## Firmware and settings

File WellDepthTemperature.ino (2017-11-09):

/*
   Arduino Sketch for a Sparkfun ESP8266 Thing Dev board
   to estimate the height of the water in our well tank
   and send this estimate to a web server.
   Water height is estimated using temperature differences read
   from a vertical line of MAX31820 temperature sensors
   glued to the tank exterior.

   Copyright (c) 2017 Bradford Needham
   { @bneedhamia , https://www.needhamia.com }

   Licensed under GPL V2
   a copy of which should have been supplied with this file.
*/
//345678901234567890123456789312345678941234567895123456789612345678971234567898

/*
   Flags to change the program behavior:
   PRINT_1_WIRE_ADDRESSES = uncomment this line to only
     print all the temperature sensors' 1-wire addresses,
     so you can copy them into the sensorAddress[] initializer.
     Comment this line out for normal Sketch behavior.
*/
//#define PRINT_1_WIRE_ADDRESSES true

#include <ESP8266WiFi.h> // Defines WiFi, the WiFi controller object
#include <WiFiClientSecure.h>
#include <EEPROM.h>   // NOTE: ESP8266 EEPROM library differs from Arduino's.
#include <OneWire.h>  // https://github.com/PaulStoffregen/OneWire
#include <DallasTemperature.h> // https://github.com/milesburton/Arduino-Temperature-Control-Library

/*
   Web Site specific constants.
     host = the hostname of the server to connect to.
     port = the HTTPS port to connect to (443 is the default).
     sslFingerprint = the SHA1 fingerprint of the SSL Certificate
       of the web site we will be connecting to.
     httpProtocol = the protocol to use. Some sites prefer HTTP/1.1.
       I use HTTP/1.0 to avoid getting a response that is
       Transfer-encoding: chunked
       which is hard to parse.
     url = the url, less https:// and the server name.
     httpAgent = a string to identify our client software.
       Replace this with whatever you like (no spaces).

     To Find the Fingerprint of a site:
     - Browse to an https: page on the desired server.
     - Copy the certificate from that page. There are instructions
       on how to do this in various browsers. Search for
       "read the certificate from a website in Chrome" (without quotes)
       or whatever web client you prefer.
     - Save the certificate in Base-64 encoded X.509
     - In git bash (or in a linux terminal window, type
       openssl x509 -noout -fingerprint -sha1 -inform pem -in certificate-file.cer
       Where "certificate-file.cer" is the filename of the certificate you saved.
     - in the response, copy the colon-separated set of numbers.
     - paste them in the sslFingerprint initializer below.
     - replace each ":" character in sslFingerprint with a space.
*/
const char *host = "needhamia.com";
const int port = 443;
const char *sslFingerprint
  = "36 33 CC B8 5C 76 B8 0D BF 79 21 0E 18 46 2E 63 D5 CD 4C FA";
const char *httpProtocol = "HTTP/1.0";
const char *url = "/webapps/welldepth/welldepthpost.php";
const char *httpAgent = "ESP8266HttpsClient";

/*
   Hardware information:

   PIN_LED_L = LOW to light the on-board LED.
     The _L suffix indicates that the pin is Active-Low.
     Active-Low because that's how the ESP8266 Thing Dev board
     on-board LED is wired.
   PIN_ONE_WIRE = the 1-Wire bus data line that all the temperature sensors
     are connected to.

   NUM_SENSORS = number of temperature sensors wired to the 1-Wire bus.

   Note about the ESP8266 Thing Dev board I/O pins: several pins are unsuitable
   to be a 1-wire bus:
     0 is connected to an on-board 10K ohm pull-up resistor.
     2 is connected to an on-board 10K ohm pull-up resistor.
     5 is connected to an on-board LED ohm and 220 ohm resistor to Vcc.
     15 is connected to an on-board 10K pull-down resistor.
     16 is not (currently) supported by the OneWire library, because
       that pin requires special treatment in the low-level I/O code.
*/
const int PIN_LED_L = 5;
const int PIN_ONE_WIRE = 4;

const int NUM_SENSORS = 12;

/*
   Time (milliseconds) per attempt to read and report the temperatures.
   Set this to, say 100L * 5 for temperature testing (e.g., to see which
   sensor is which by heating one and seeing which sensor temperature changes).
   Set this to over 5 minutes (1000L * 60L * 5) for normal operation,
   so you don't overwhelm the server.
*/
const long MS_PER_TEMPERATURE_REQUEST = 1000L * 60;

/*
   The resolution (number of bits) to set the temperature sensors to.
   12 is the maximum; 9 is the minimum.
   Higher resolution takes longer (see the Max31820 datasheet for details)
   but is more precise.
*/
const uint8_t MAX31820_RESOLUTION_BITS = 12;

/*
   The EEPROM layout, starting at START_ADDRESS, is:
   String[EEPROM_WIFI_SSID_INDEX] = WiFi SSID. A null-terminated string
   String[EEPROM_WIFI_PASS_INDEX] = WiFi Password. A null-terminated string 1
   String[EEPROM_WIFI_TIMEOUT_SECS_INDEX = WiFi connection timeout, in seconds,
     as an Ascii string.
   String[EEPROM_WEB_USERNAME] = the HTTPS POST username parameter to send.
   String[EEPROM_WEB_PASSWORD] = the HTTPS POST password parameter to send.
   EEPROM_END_MARK

   To write these values, use the Sketch write_eeprom_strings.
   See https://github.com/bneedhamia/write_eeprom_strings
   Modify that Sketch, replacing the initialization of STRING_NAME[] with
   the following lines:

  const char *STRING_NAME[] = {
  "SSID",
  "Password",
  "Timeout(seconds)",
  "username",
  "password",
  0
  };

*/
const int START_ADDRESS = 0;      // The first EEPROM address to read from.
const byte EEPROM_END_MARK = 255; // marks the end of the data we wrote to EEPROM
const int EEPROM_MAX_STRING_LENGTH = 120; // max string length in EEPROM
const int EEPROM_WIFI_SSID_INDEX = 0;
const int EEPROM_WIFI_PASS_INDEX = 1;
const int EEPROM_WIFI_TIMEOUT_SECS_INDEX = 2;
const int EEPROM_WEB_USERNAME_INDEX = 3;
const int EEPROM_WEB_PASSWORD_INDEX = 4;

/*
   The states of the state machine that loop() runs.

   state = the current state of the machine. A STATE_* value.
   stateBegunMs = if needed, the time (millis() we entered this state.

   STATE_ERROR = an unrecoverable error has occurred. We stop.
   STATE_WAITING_FOR_TEMPERATURES = we've issued a command to the sensors
     to read the temperature, and are waiting for the time to read
     their responses.
     For example, a 12-bit temperature read requires 750ms.
     stateBegunMs = time (millis()) we entered this state.
   STATE_WAITING_FOR_NEXT_READ = we're waiting to request temperatures again.
     stateBegunMs = time (millis()) we entered this state.
*/

const uint8_t STATE_ERROR = 0;
const uint8_t STATE_WAITING_FOR_TEMPERATURES = 1;
const uint8_t STATE_WAITING_FOR_NEXT_READ = 2;
uint8_t state;
unsigned long stateBegunMs = 0L;

/*
   client = manages the HTTPS connection to the web site.
   wire = The 1-Wire interface manager.

   NOTE: because the ESP8266 WiFi operates in the background,
     loop() must not take a long time.
     In particular, never (even in setup()) call any delay() greater than
     a few hundred milliseconds.
*/
WiFiClientSecure client;
OneWire wire(PIN_ONE_WIRE);
DallasTemperature wireDevices(&wire);

/*
   WiFi access point parameters, read from EEPROM.

   wifiSsid = SSID of the network to connect to.
   wifiPassword = Password of the network.
   wifiTimeoutMs = Wifi connection timeout, in milliseconds.
*/
char *wifiSsid;
char *wifiPassword;
long wifiTimeoutMs;

/*
   HTTPS POST private parameters, read from EEPROM.

   webUsername = the POST 'username' parameter.
   webPassword = the POST 'password' parameter.
*/
char *webUsername;
char *webPassword;

/*
   sensorAddress[] = the 1-wire address of each sensor on the 1-wire bus,
   in order of distance from the controller ([0] = closest).
   Note: this order is not the order the sensors are returned by a search().

   I created this table by:
   1) Uncommenting PRINT_1_WIRE_ADDRESSES (above)
   2) Running the Sketch, and copying and pasting the output here.
   3) Commenting out PRINT_1_WIRE_ADDRESSES (above)
   4) Starting the Sketch.
   5) In turn, heating (or cooling) one sensor and seeing which position
     that sensor is in, based on the printed temperatures.
   6) rearranging the rows here to order by distance from the processor.
*/
DeviceAddress sensorAddress[NUM_SENSORS] = {
  {0x28, 0xC6, 0x8A, 0xA8, 0x7, 0x0, 0x0, 0x8A},
  {0x28, 0x52, 0x93, 0xA8, 0x7, 0x0, 0x0, 0x68},
  {0x28, 0x5A, 0xC6, 0xA8, 0x7, 0x0, 0x0, 0x8E},
  {0x28, 0xD2, 0xBB, 0xA8, 0x7, 0x0, 0x0, 0x44},
  {0x28, 0xB8, 0xB8, 0xA8, 0x7, 0x0, 0x0, 0x6},
  {0x28, 0x76, 0xCA, 0xA8, 0x7, 0x0, 0x0, 0x64},
  {0x28, 0xD6, 0xCE, 0xA8, 0x7, 0x0, 0x0, 0x27},
  {0x28, 0xC8, 0xCC, 0xA8, 0x7, 0x0, 0x0, 0xEC},
  {0x28, 0x48, 0xCE, 0xA8, 0x7, 0x0, 0x0, 0x85},
  {0x28, 0x40, 0x90, 0xA8, 0x7, 0x0, 0x0, 0x13},
  {0x28, 0xF9, 0x8D, 0xA8, 0x7, 0x0, 0x0, 0x12},
  {0x28, 0xAB, 0xA8, 0xA8, 0x7, 0x0, 0x0, 0x78}
};

/*
   The results of measurement:

   wellDepthM = the depth of well water, in meters from the bottom of the tank,
    or -1 if the depth calculation failed.
    Note: the accuracy of this value is likely about 20cm.
   wellTempC[] = the temperature (degrees Celsius) read from each sensor,
    or TODO pick a number if the sensor failed.
    Indexed by the sensor number in sensorAddress[].
*/
float wellDepthM;
float wellTempC[NUM_SENSORS];

// Called once automatically on Reset.
void setup() {
  Serial.begin(9600);
  delay(100); // give the Serial port time to power up.
  Serial.println(F("Reset."));

  // Set up our pins.

  pinMode(PIN_LED_L, OUTPUT);
  digitalWrite(PIN_LED_L, HIGH); // ESP8266 Thing Dev LED is Active Low
  // PIN_ONE_WIRE is managed by the OneWire library.

  wireDevices.begin();  // searches the 1-wire bus for devices.

#if defined(PRINT_1_WIRE_ADDRESSES)
  // Report the device addresses, in no particular order, and quit.
  print1WireAddresses();

  state = STATE_ERROR;
  return;
#endif

  /*
     Read the wifi parameters from EEPROM, if they're there.
     Convert the timeout from a string and Seconds
       to a long number of milliseconds.
  */
  wifiSsid = readEEPROMString(START_ADDRESS, EEPROM_WIFI_SSID_INDEX);
  wifiPassword = readEEPROMString(START_ADDRESS, EEPROM_WIFI_PASS_INDEX);
  char *timeoutText = readEEPROMString(START_ADDRESS
                                       , EEPROM_WIFI_TIMEOUT_SECS_INDEX);
  if (wifiSsid == 0 || wifiPassword == 0 || timeoutText == 0) {
    Serial.println(F("EEPROM not initialized."));

    state = STATE_ERROR;
    return;
  }
  wifiTimeoutMs = atol(timeoutText) * 1000L;
  if (wifiTimeoutMs == 0L) {
    Serial.print(F("Garbled EEPROM WiFi timeout: "));
    Serial.println(timeoutText);

    state = STATE_ERROR;
    return;
  }

  /*
     Read the Web Service username and password from EEPROM
  */
  webUsername = readEEPROMString(START_ADDRESS, EEPROM_WEB_USERNAME_INDEX);
  webPassword = readEEPROMString(START_ADDRESS, EEPROM_WEB_PASSWORD_INDEX);
  if (webUsername == 0 || webPassword == 0) {
    Serial.println(F("EEPROM not initialized."));

    state = STATE_ERROR;
    return;
  }

  // Do the one-time WiFi setup and connection
  WiFi.mode(WIFI_STA);    // Station (Client), not soft AP or dual mode.
  WiFi.setAutoConnect(false); // don't connect until I say
  WiFi.setAutoReconnect(true); // if the connection ever drops, reconnect.
  if (!connectToAccessPoint(wifiSsid, wifiPassword, wifiTimeoutMs)) {
    state = STATE_ERROR;
    return;
  }

  /*
     Set up the temperature sensors:
     Set the digital temperature resolution.
     Set the library to have requestTemperatures() return immediately
       rather than waiting the (too long for our WiFi) conversion time.
  */
  wireDevices.setResolution(MAX31820_RESOLUTION_BITS);
  wireDevices.setWaitForConversion(false);

  // Start the first temperature reading.
  wireDevices.requestTemperatures();
  state = STATE_WAITING_FOR_TEMPERATURES;
  stateBegunMs = millis();
}

// Called repeatedly, automatically.
void loop() {
  long nowMs;

  nowMs = millis();

  switch (state) {
    case STATE_ERROR:
      // Blink the led.
      if (nowMs % 1000 < 500) {
        digitalWrite(PIN_LED_L, LOW);
      } else {
        digitalWrite(PIN_LED_L, HIGH);
      }
      break;

    case STATE_WAITING_FOR_TEMPERATURES:
      if ((long) (nowMs - stateBegunMs)
          < wireDevices.millisToWaitForConversion(MAX31820_RESOLUTION_BITS)) {
        return; // wait more.
      }

      // The temperatures are ready. Read and print them.
      for (int i = 0; i < NUM_SENSORS; ++i) {
        wellTempC[i] = wireDevices.getTempC(sensorAddress[i]);

        if (i != 0) {
          Serial.print(", ");
        }
        if (wellTempC[i] <= DEVICE_DISCONNECTED_C) {
          Serial.print("NC");
        } else {
          Serial.print(wellTempC[i], 2);
        }
      }
      Serial.println();

      // Calculate the well depth
      // For now, just leave a dummy value.
      wellDepthM = -1.0;

      // Report all our data (that we have) to the web server.
      if (doHttpsPost()) {
        digitalWrite(PIN_LED_L, HIGH); // success: turn off the LED.
      } else {
        digitalWrite(PIN_LED_L, LOW); // failure: turn on the LED.
      }

      // Wait until it's time to request the temperatures again.
      state = STATE_WAITING_FOR_NEXT_READ;
      stateBegunMs = nowMs;

      break;

    case STATE_WAITING_FOR_NEXT_READ:
      if ((long) (nowMs - stateBegunMs) < MS_PER_TEMPERATURE_REQUEST) {
        return; // wait more.
      }

      // Request the sensors to read their temperatures.
      wireDevices.requestTemperatures();
      state = STATE_WAITING_FOR_TEMPERATURES;
      stateBegunMs = millis();
      break;

    default:
      Serial.print("unknown state: ");
      Serial.println(state);
      state = STATE_ERROR;
      break;
  }
}

/*
    Uploads the temperatures and estimated well depth.
    Uses:
      webUsername, webPassword
      wellDepthM
      wellTempC[]
      and the server information (host, post, etc.)

    Returns true if successful, false otherwise.
*/
boolean doHttpsPost() {
  char content[1024];  // Buffer for the content of the POST request.
  char *pContent;  // a pointer into content[]
  char ch;

  // Build the content of the POST. That is, the parameters.

  strcpy(content, "");

  strcat(content, "username=");
  strcat(content, webUsername); //TODO urlencode

  strcat(content, "&");
  strcat(content, "password=");
  strcat(content, webPassword); // TODO urlencode.

  if (wellDepthM > 0.0) {
    strcat(content, "&");
    strcat(content, "well_depth_m=");
    floatcat(content, wellDepthM);
  }

  for (int i = 0; i < NUM_SENSORS; ++i) {
    if (wellTempC[i] > DEVICE_DISCONNECTED_C) {
      strcat(content, "&");
      strcat(content, "well_temp_c");
      pContent = content + strlen(content);
      itoa(i, pContent, 10);
      strcat(content, "=");
      floatcat(content, wellTempC[i]);
    }
  }

  // Perform the Post

  if (!client.connect(host, port)) {
    Serial.print("Failed to connect to ");
    Serial.print(host);
    Serial.print(" port ");
    Serial.println(port);
    return false;
  }
  Serial.print("Connected to ");
  Serial.println(host);

  if (!client.verify(sslFingerprint, host)) {
    Serial.print("Fingerprint doesn't match certificate for ");
    Serial.println(host);
    client.stop();
    return false;
  }

  client.print("POST ");
  client.print(url);
  client.print(" ");
  client.println(httpProtocol);

  client.print("Host: ");
  client.println(host);

  client.print("User-Agent: ");
  client.println(httpAgent);

  client.println("Connection: close");

  client.println("Content-Type: application/x-www-form-urlencoded");

  client.print("Content-Length: ");
  client.println(strlen(content));

  client.println();  // blank line indicates the end of the HTTP headers.

  // send the content: the POST parameters.
  client.print(content);

  Serial.println("Reading response:");
  while (client.connected()) {
    if (client.available()) {
      ch = client.read();
      Serial.print(ch);
    }
    delay(1); // to yield the processor for a moment.
  }

  Serial.println();
  Serial.println("connection closed.");

  client.stop();

  return true;
}

/*
   Append (concatenate) the given floating-point number
   as a string to the given buffer.

   buffer = a space to concatenate into. It must contain a null-terminated
    set of characters.
   f = the floating point number to convert into a set of characters.

*/
void floatcat(char *buffer, float f) {
  char *p;
  long l;

  p = buffer + strlen(buffer);

  // Convert the sign.
  if (f < 0.0) {
    *p++ = '-';
    f = -f;
  }

  // Convert the integer part.
  l = (long) f;
  f -= (float) l;
  itoa(l, p, 10);
  p += strlen(p);

  // Convert the first 2 digits of the fraction.
  *p++ = '.';
  f *= 100.0;
  itoa((long) f, p, 10);
}

/*
   Prints the 1-wire address of each device found on the 1-wire bus.
   The output is in a form that can be copied and pasted into an array
   initializer.

   Returns the number of devices on the bus if successful,
   0 if there is an error.
*/
uint8_t print1WireAddresses() {
  uint8_t numDevices;

  numDevices = wireDevices.getDeviceCount();
  Serial.print(numDevices);
  Serial.println(" temperature sensors responded:");

  DeviceAddress address;
  for (int i = 0; i < numDevices; ++i) {
    if (!wireDevices.getAddress(address, i)) {
      Serial.print("Sensor[");
      Serial.print(i);
      Serial.println("] was not found.");
      return 0;
    }
    Serial.print("  ");
    print1WireAddress(address);
    if (i < numDevices - 1) {
      Serial.print(",");
    }
    Serial.println();
  }

  return numDevices;
}

/*
   Prints a device address in a form that can be pasted into Arduino code
   as an initializer of a DeviceAddress variable.
*/
void print1WireAddress(DeviceAddress addr) {
  Serial.print("{");
  for (int i = 0; i < 8; ++i) {
    if (i != 0) {
      Serial.print(", ");
    }
    Serial.print("0x");
    Serial.print(addr[i], HEX);
  }
  Serial.print("}");
}

/*
   Connect to the local WiFi Access Point.
   The Auto Reconnect feature of the ESP8266 should keep us connected.

   ssid = the WiFi Access Point to connect to.
   pass = the password for that Access Point.
   timeoutMs = maximum time (milliseconds) to wait for the connection.

   Returns true if successful; false if a nonrecoverable error occurred.
*/
boolean connectToAccessPoint(char *ssid, char *pass, long timeoutMs) {
  unsigned long startTimeMs;  // time (millis()) when we started connecting.
  unsigned long now;  // the current time (millis())

  Serial.print(F("Connecting to "));
  Serial.println(ssid);

  startTimeMs = millis();
  WiFi.begin(ssid, wifiPassword);

  // Wait for the connection or timeout.
  int wifiStatus = WiFi.status();
  while (wifiStatus != WL_CONNECTED)
  {
    now = millis();

    if (wifiStatus == WL_NO_SSID_AVAIL) {
      // AP is offline.
      Serial.print(F("Unable to find "));
      Serial.println(ssid);
      return false;
    }
    if (wifiStatus == WL_CONNECT_FAILED) {
      // bad password
      Serial.print(F("Password incorrect for "));
      Serial.println(ssid);
      return false;
    }
    if ((long) (now - startTimeMs) > timeoutMs) {
      // Connection has taken too long
      Serial.print(F("Timeout connecting to "));
      Serial.println(ssid);
      return false;
    }

    /*
       The WiFi stack is still trying to connect.
       Give it a moment and check again.
    */

    delay(100);
    wifiStatus = WiFi.status();
  }

  Serial.print(F("Connected, IP address: "));
  Serial.println(WiFi.localIP());

  return true;
}

/********************************
   From https://github.com/bneedhamia/write_eeprom_strings example
*/
/*
   Reads a string from EEPROM.  Copy this code into your program that reads EEPROM.

   baseAddress = EEPROM address of the first byte in EEPROM to read from.
   stringNumber = index of the string to retrieve (string 0, string 1, etc.)

   Assumes EEPROM contains a list of null-terminated strings,
   terminated by EEPROM_END_MARK.

   Returns:
   A pointer to a dynamically-allocated string read from EEPROM,
   or null if no such string was found.
*/
char *readEEPROMString(int baseAddress, int stringNumber) {
  int start;   // EEPROM address of the first byte of the string to return.
  int length;  // length (bytes) of the string to return, less the terminating null.
  char ch;
  int nextAddress;  // next address to read from EEPROM.
  char *result;     // points to the dynamically-allocated result to return.
  int i;


#if defined(ESP8266)
  EEPROM.begin(512);
#endif

  nextAddress = START_ADDRESS;
  for (i = 0; i < stringNumber; ++i) {

    // If the first byte is an end mark, we've run out of strings too early.
    ch = (char) EEPROM.read(nextAddress++);
    if (ch == (char) EEPROM_END_MARK) {
#if defined(ESP8266)
      EEPROM.end();
#endif
      return (char *) 0;  // not enough strings are in EEPROM.
    }

    // Read through the string's terminating null (0).
    int length = 0;
    while (ch != '\0' && length < EEPROM_MAX_STRING_LENGTH - 1) {
      ++length;
      ch = EEPROM.read(nextAddress++);
    }
  }

  // We're now at the start of what should be our string.
  start = nextAddress;

  // If the first byte is an end mark, we've run out of strings too early.
  ch = (char) EEPROM.read(nextAddress++);
  if (ch == (char) EEPROM_END_MARK) {
#if defined(ESP8266)
    EEPROM.end();
#endif
    return (char *) 0;  // not enough strings are in EEPROM.
  }

  // Count to the end of this string.
  length = 0;
  while (ch != '\0' && length < EEPROM_MAX_STRING_LENGTH - 1) {
    ++length;
    ch = EEPROM.read(nextAddress++);
  }

  // Allocate space for the string, then copy it.
  result = new char[length + 1];
  nextAddress = start;
  for (i = 0; i < length; ++i) {
    result[i] = (char) EEPROM.read(nextAddress++);
  }
  result[i] = '\0';

  return result;
}

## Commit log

2017-10-21 Initial commit. Much code to write.
    [BillOfMaterials.ods]
2017-10-21 Corrected the name of the Sketch
    [WellDepthTemperature.ino]
2017-10-21 now reads temperature from 6 sensors
2017-10-22 Updated the Bill of Materials; now running 12 sensors
    [BillOfMaterials.ods]
2017-10-22 Messed about a lot. Added WiFi error checks and timeout.
    [WellDepthTemperature.ino]
2017-10-24 ordered RJ45 stuff for the 1-wire bus
2017-10-26 Updated the Bill of Materials, project state
    [BillOfMaterials.ods]
2017-11-01 added wifi timeout; updated bill of materials for RJ45
    [BillOfMaterials.ods]
2017-11-04 switched to a POST request. Did a simple Post parameter test.
2017-11-05 sensor values now get to the PHP page.
2017-11-05 database storage of temperatures now works.
2017-11-09 added LED for https post failure; now testing in the well room
    [WellDepthTemperature.ino]
2017-11-19 checkpoint designing 3D printed parts
    [BreadboardCase.FCStd, ThreeJackCase.FCStd]
2017-11-20 updated Bill of Materials for 3D printed cases; doing more 3d
    [BillOfMaterials.ods, BreadboardCase.FCStd, ThreeJackCase.FCStd]
2017-11-27 added STL files for the RJ45 case. Soldered a lot.
    [ThreeJackCaseBase.stl, ThreeJackCaseLid.stl]
2017-12-03 Added Fritzing diagram
    [WellDepthTemperature.fzz]
